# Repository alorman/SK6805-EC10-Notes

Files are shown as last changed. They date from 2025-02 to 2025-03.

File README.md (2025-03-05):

# SK6805-EC10-Notes

Notes on the __smallest__ availible addressable LED to date!

**Author's note:** While you will definitely need a loupe or microscope to even see what you're doing, these can be a bit easier to solder than the 3535 and other large sizes. If you choose a low-temp solder and gently use hot air, you can get each LED to snap into place onto the solder pads. 

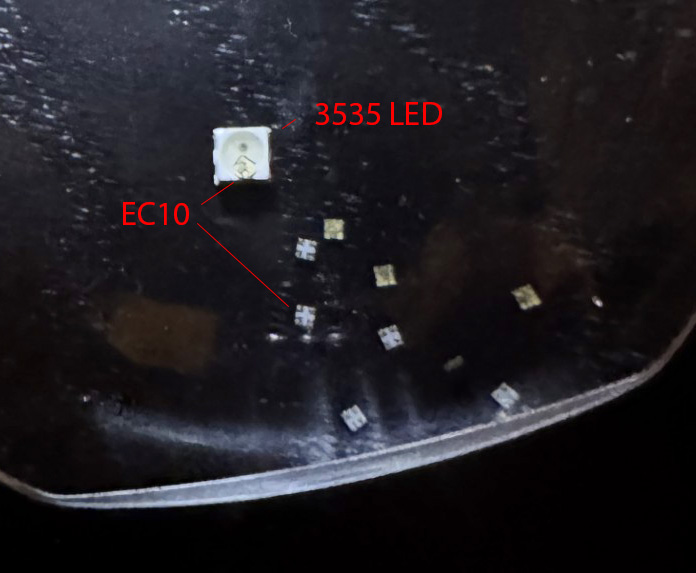
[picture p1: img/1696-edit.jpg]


Above, you can see the EC10 modules next to a 3535 LED. These guys are SMOL.

## Purchasing
Adadfruit sells thes units as [Part Number 5849](https://www.adafruit.com/product/5849).
They can also be purchased on AliExpress in volume.  
Buy extras, you will lose some of these, since breathing on them the wrong way blows them away. 

## Datasheet 
[Datasheet from Adafruit](https://cdn-shop.adafruit.com/product-files/5849/SK6805-EC10-000_REV.01_EN.pdf)

## KiCad Files
I made footprint and symbol files availible for the EC10s.  
They can be found in `\SK6805-EC10-kicad-libraries`  
There is no 3d model included, because it didn't add much and made it much harder to see if the mask was right.  

## Test Fixture
Since I couldn't find a pre-made strip of the EC10 modules, I decided to make one. This can be easily fabbed from your favorite fab house. 
Full KiCad 8 files can be found in `\EC10-Test-PCB` 

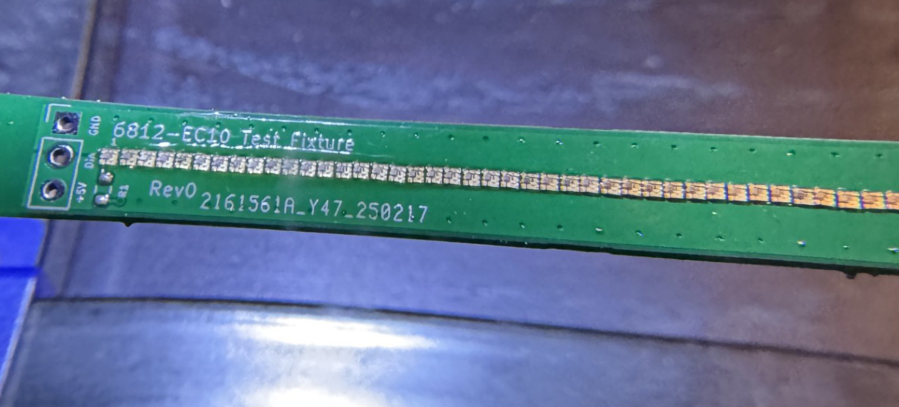
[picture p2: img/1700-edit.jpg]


## Power Profiling
I soldered 48 of the modules to my test fixture (2 got blown away by the hot air gun).
**Note** use low-temp solder and gentle hot air. I was able to swim the modules into place on flux without breaking any of the lenses. At least on the 1515, if you get them too hot, the lens/case breaks. 

### Setup
I connected my 48x strip to a Siglent SPD-3303X PSU that quotes current reading of +- 0.3% + 10ma, while there may be tiny test errors, this should provide a good bassis for power calculations. 

I used 5V as a supply voltage.

### Methodology
I cycled Red, Green then Blue through 0-255 individually, while recording the power usage. Then I ran all three together to make white from 0-255. 

The code can be found in `\test-code` and is designed for a Teensy, but would work on any Arduino. 

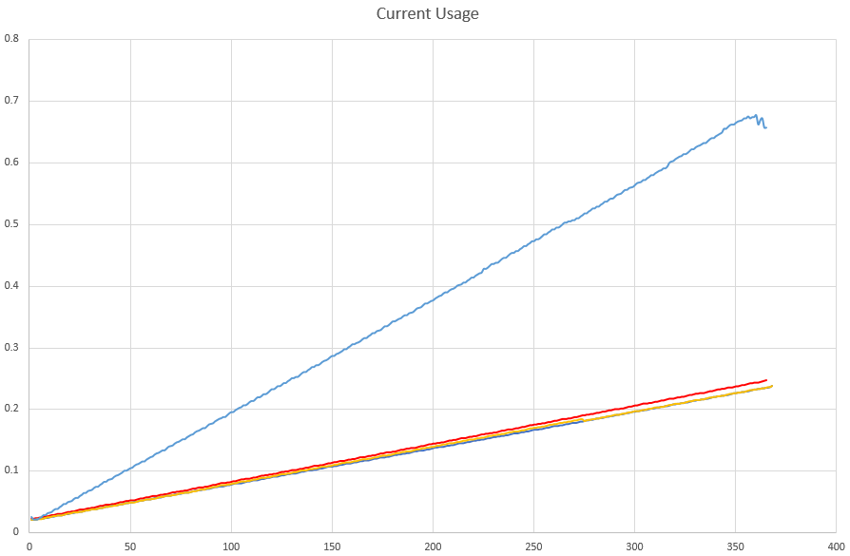
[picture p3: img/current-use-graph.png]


We can see a linear and similar progression for R, G and B. Correspondingly, we see that consumption roughly tripling for white, which makes sense.

The idle current can also be charachterized from the first few data points.

## Power Formula

### I<sub>consumed</sub>=((R+B+G)*0.013838)+0.4791

Where:  
`Iconsumed` = Current consumed **per LED** in mA  
`(R+B+G)` = Values for R, G and B in 0-255  
`0.4791` = Idle current draw in mA per module  

## Compared To 1515 Size
These are a good amount smaller than the pettite 1515 size. I documented the features of those [on this repo](https://github.com/alorman/sk6805-1515-info).

Here are the two compared:  

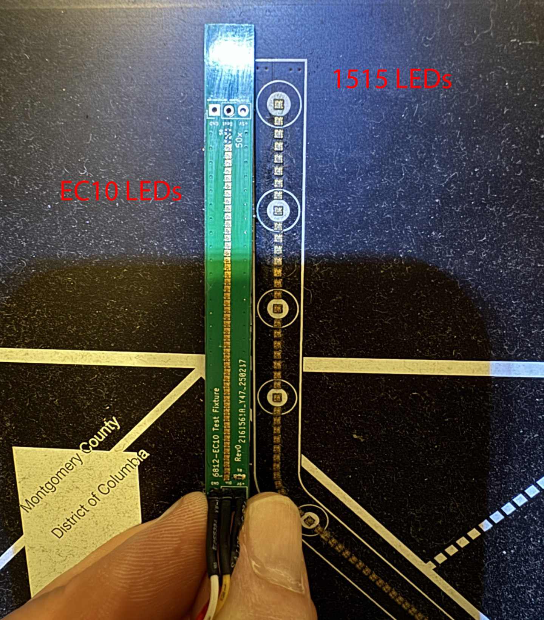
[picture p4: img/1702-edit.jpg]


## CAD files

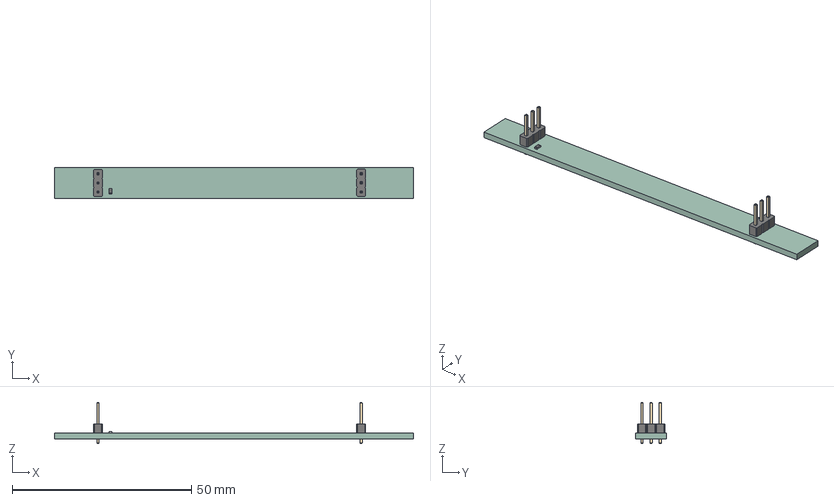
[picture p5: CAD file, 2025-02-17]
EC10-Test-PCB/Outputs/STEP/EC10-Test-PCB.step
100.1 x 8.70 x 11.5 mm
R_0603_1608Metric
PinHeader_1x03_P254mm_Vertical x 2
EC10-Test-PCB_PCB

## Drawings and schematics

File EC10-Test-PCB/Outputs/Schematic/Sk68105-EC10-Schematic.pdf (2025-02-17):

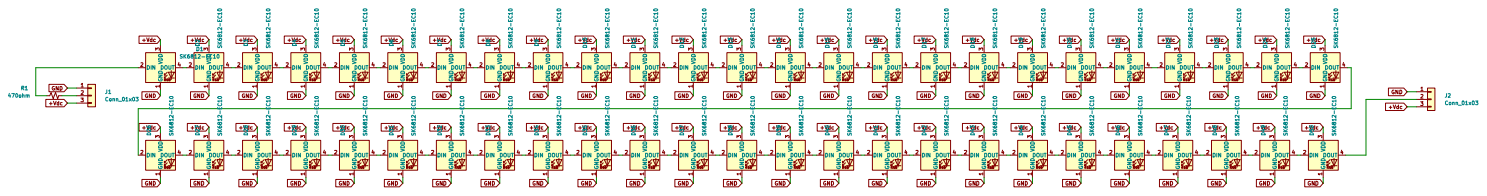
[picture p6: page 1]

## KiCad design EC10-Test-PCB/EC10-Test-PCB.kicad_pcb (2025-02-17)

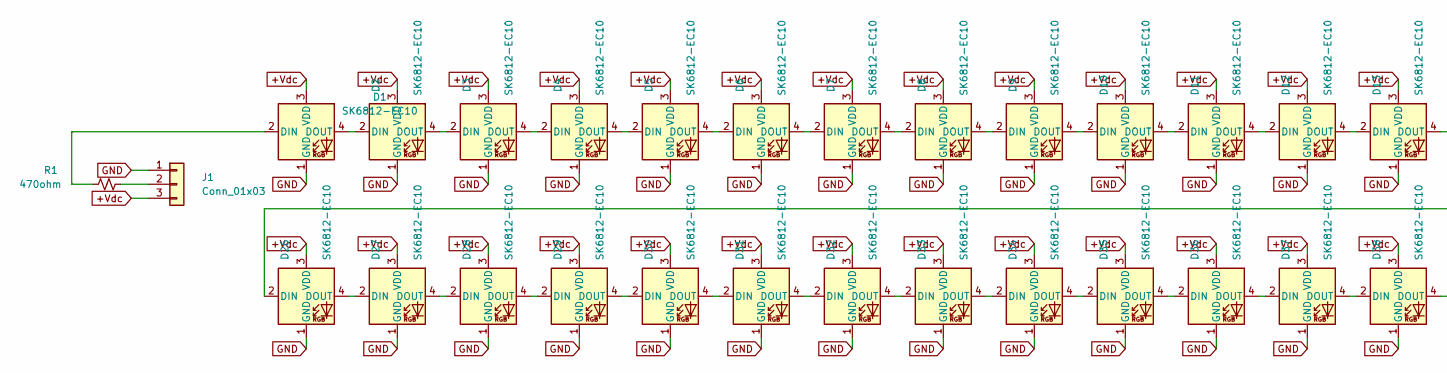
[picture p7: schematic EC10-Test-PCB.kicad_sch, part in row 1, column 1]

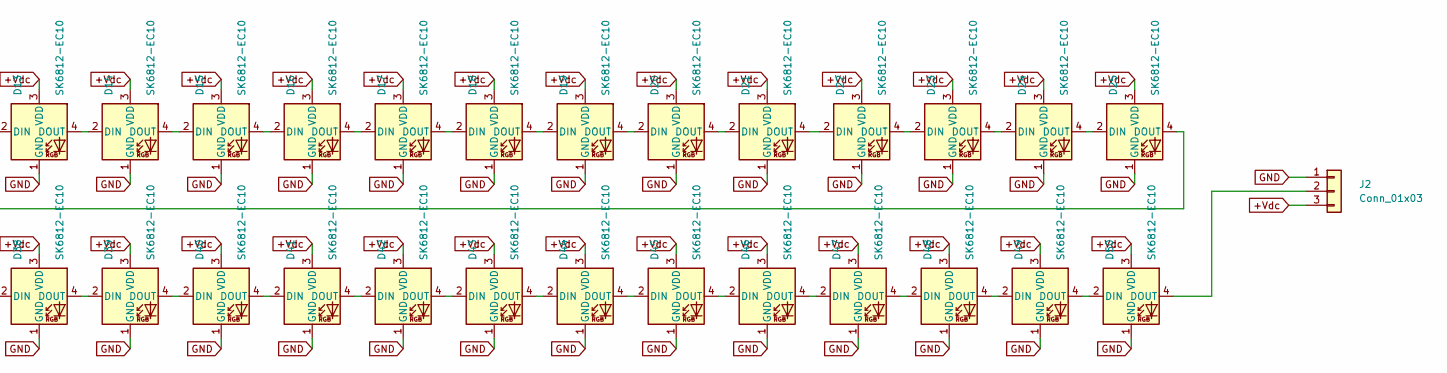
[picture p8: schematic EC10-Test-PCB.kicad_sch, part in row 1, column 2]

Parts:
D1, D2, D3, D4, D5, D6, D7, D8, D9, D10, D11, D12, D13, D14, D15, D16, D17, D18, D19, D20, D21, D22, D23, D24, D25, D26, D27, D28, D29, D30, D31, D32, D33, D34, D35, D36, D37, D38, D39, D40, D41, D42, D43, D44, D45, D46, D47, D48, D49, D50: SK6812-EC10; SK6805-EC10
J1, J2: Conn_01x03; PinHeader_1x03_P2.54mm_Vertical
R1: 470ohm; R_0603_1608Metric

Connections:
+Vdc: D1.3 (VDD), D2.3 (VDD), D3.3 (VDD), D4.3 (VDD), D5.3 (VDD), D6.3 (VDD), D7.3 (VDD), D8.3 (VDD), D9.3 (VDD), D10.3 (VDD), D11.3 (VDD), D12.3 (VDD), D13.3 (VDD), D14.3 (VDD), D15.3 (VDD), D16.3 (VDD), D17.3 (VDD), D18.3 (VDD), D19.3 (VDD), D20.3 (VDD), D21.3 (VDD), D22.3 (VDD), D23.3 (VDD), D24.3 (VDD), D25.3 (VDD), D26.3 (VDD), D27.3 (VDD), D28.3 (VDD), D29.3 (VDD), D30.3 (VDD), D31.3 (VDD), D32.3 (VDD), D33.3 (VDD), D34.3 (VDD), D35.3 (VDD), D36.3 (VDD), D37.3 (VDD), D38.3 (VDD), D39.3 (VDD), D40.3 (VDD), D41.3 (VDD), D42.3 (VDD), D43.3 (VDD), D44.3 (VDD), D45.3 (VDD), D46.3 (VDD), D47.3 (VDD), D48.3 (VDD), D49.3 (VDD), D50.3 (VDD), J1.3, J2.3
GND: D1.1 (GND), D2.1 (GND), D3.1 (GND), D4.1 (GND), D5.1 (GND), D6.1 (GND), D7.1 (GND), D8.1 (GND), D9.1 (GND), D10.1 (GND), D11.1 (GND), D12.1 (GND), D13.1 (GND), D14.1 (GND), D15.1 (GND), D16.1 (GND), D17.1 (GND), D18.1 (GND), D19.1 (GND), D20.1 (GND), D21.1 (GND), D22.1 (GND), D23.1 (GND), D24.1 (GND), D25.1 (GND), D26.1 (GND), D27.1 (GND), D28.1 (GND), D29.1 (GND), D30.1 (GND), D31.1 (GND), D32.1 (GND), D33.1 (GND), D34.1 (GND), D35.1 (GND), D36.1 (GND), D37.1 (GND), D38.1 (GND), D39.1 (GND), D40.1 (GND), D41.1 (GND), D42.1 (GND), D43.1 (GND), D44.1 (GND), D45.1 (GND), D46.1 (GND), D47.1 (GND), D48.1 (GND), D49.1 (GND), D50.1 (GND), J1.1, J2.1
unnamed: D1.2 (DIN), R1.1
unnamed: D1.4 (DOUT), D2.2 (DIN)
unnamed: D2.4 (DOUT), D3.2 (DIN)
unnamed: D3.4 (DOUT), D4.2 (DIN)
unnamed: D4.4 (DOUT), D5.2 (DIN)
unnamed: D5.4 (DOUT), D6.2 (DIN)
unnamed: D6.4 (DOUT), D7.2 (DIN)
unnamed: D7.4 (DOUT), D8.2 (DIN)
unnamed: D8.4 (DOUT), D9.2 (DIN)
unnamed: D9.4 (DOUT), D10.2 (DIN)
unnamed: D10.4 (DOUT), D11.2 (DIN)
unnamed: D11.4 (DOUT), D12.2 (DIN)
unnamed: D12.4 (DOUT), D13.2 (DIN)
unnamed: D13.4 (DOUT), D14.2 (DIN)
unnamed: D14.4 (DOUT), D15.2 (DIN)
unnamed: D15.4 (DOUT), D16.2 (DIN)
unnamed: D16.4 (DOUT), D17.2 (DIN)
unnamed: D17.4 (DOUT), D18.2 (DIN)
unnamed: D18.4 (DOUT), D19.2 (DIN)
unnamed: D19.4 (DOUT), D20.2 (DIN)
unnamed: D20.4 (DOUT), D21.2 (DIN)
unnamed: D21.4 (DOUT), D22.2 (DIN)
unnamed: D22.4 (DOUT), D23.2 (DIN)
unnamed: D23.4 (DOUT), D24.2 (DIN)
unnamed: D24.4 (DOUT), D25.2 (DIN)
unnamed: D25.4 (DOUT), D26.2 (DIN)
unnamed: D26.4 (DOUT), D27.2 (DIN)
unnamed: D27.4 (DOUT), D28.2 (DIN)
unnamed: D28.4 (DOUT), D29.2 (DIN)
unnamed: D29.4 (DOUT), D30.2 (DIN)
unnamed: D30.4 (DOUT), D31.2 (DIN)
unnamed: D31.4 (DOUT), D32.2 (DIN)
unnamed: D32.4 (DOUT), D33.2 (DIN)
unnamed: D33.4 (DOUT), D34.2 (DIN)
unnamed: D34.4 (DOUT), D35.2 (DIN)
unnamed: D35.4 (DOUT), D36.2 (DIN)
unnamed: D36.4 (DOUT), D37.2 (DIN)
unnamed: D37.4 (DOUT), D38.2 (DIN)
unnamed: D38.4 (DOUT), D39.2 (DIN)
unnamed: D39.4 (DOUT), D40.2 (DIN)
unnamed: D40.4 (DOUT), D41.2 (DIN)
unnamed: D41.4 (DOUT), D42.2 (DIN)
unnamed: D42.4 (DOUT), D43.2 (DIN)
unnamed: D43.4 (DOUT), D44.2 (DIN)
unnamed: D44.4 (DOUT), D45.2 (DIN)
unnamed: D45.4 (DOUT), D46.2 (DIN)
unnamed: D46.4 (DOUT), D47.2 (DIN)
unnamed: D47.4 (DOUT), D48.2 (DIN)
unnamed: D48.4 (DOUT), D49.2 (DIN)
unnamed: D49.4 (DOUT), D50.2 (DIN)
unnamed: D50.4 (DOUT), J2.2
unnamed: J1.2, R1.2

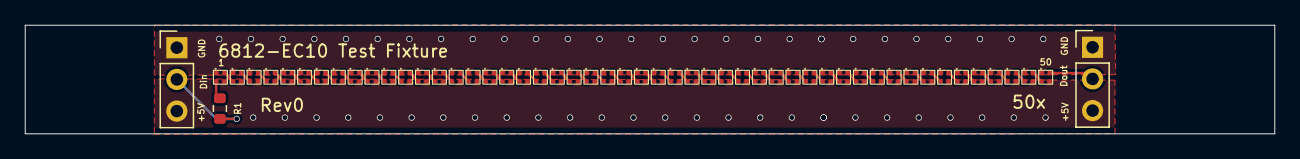
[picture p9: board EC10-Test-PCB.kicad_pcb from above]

Board: 2 copper layers, 100.1 x 8.7 mm, 53 parts (0 on the bottom side), 54 nets.

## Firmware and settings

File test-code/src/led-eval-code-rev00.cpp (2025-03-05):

// A test pogram to have neopixels move on user input.

#include <Adafruit_NeoPixel.h>

//Define LED Pin
#define LED_PIN  26

//Define LED Count
#define LED_COUNT 48

// //Define Touch Pin
// #define TOUCH_PIN A9

//functions declarations 
void colorIncrement(Adafruit_NeoPixel &strip, uint16_t timeInterval);

//Establish the neopixle object
Adafruit_NeoPixel TestStrip(LED_COUNT, LED_PIN, NEO_GRB + NEO_KHZ800);

//Define LED Variables
uint8_t RGBcolor [] = {0,0,0};
uint32_t TestColorRGB = TestStrip.Color(RGBcolor[0],RGBcolor[1],RGBcolor[2]);

uint16_t LEDColorH = 100;
uint8_t LEDColorS = 100;
uint8_t LEDColorV = 0;

uint32_t LEDColorHSV = 0;
uint32_t ConvertedHSVtoRGB = 0;

//Define touch variables
uint8_t touchValue = 0;

void setup() {
  Serial.begin(115200); //establish serial port
  delay(1500);
  TestStrip.begin();
  TestStrip.setBrightness(255); //using this to have the values we input be fully deterministic
  TestStrip.clear();
  TestStrip.show();
  
  Serial.println("Setup Complete...");
  Serial.println("Starting..."); //nice confirmation that it's actually working
  delay(500);
}

void loop() {
  // while (touchRead(TOUCH_PIN) > 1800) {
  //   ConvertedHSVtoRGB = TestStrip.gamma32(TestStrip.ColorHSV(LEDColorH, LEDColorS, LEDColorV));
  //   TestStrip.fill(ConvertedHSVtoRGB);
  //   uint8_t ColorR = ConvertedHSVtoRGB >> 16;  
  //   uint8_t ColorG = ConvertedHSVtoRGB >> 8;
  //   uint8_t ColorB = ConvertedHSVtoRGB;
  //   //Serial.println((String)"LED Value is H:" + LEDColorH + " S:" + LEDColorS + " V:" + LEDColorV);
  //   Serial.println((String)"Converted RGB is:" + ConvertedHSVtoRGB + " R:" + ColorR + " G:" + ColorB + " B:" + ColorB);
  //   TestStrip.show();
  //   delay(1000);
  //   Serial.println("Great! Next!");
  //   LEDColorV++;
  // }
  colorIncrement(TestStrip, 750);

}

void colorIncrement(Adafruit_NeoPixel &strip, uint16_t timeInterval) {
  // 1. Increment Red
  for (int i = 0; i < 256; i++) {
    strip.fill(strip.Color(i, 0, 0), 0, strip.numPixels());
    strip.show();

    // Print serial feedback
    Serial.print("R=");
    Serial.print(i);
    Serial.print(", G=0, B=0  ");
    Serial.println(" (Incrementing Red)");

    delay(timeInterval);
  }
  // Go Black
  strip.fill(strip.Color(0, 0, 0), 0, strip.numPixels());
  strip.show();
  Serial.println("All pixels set to Black");
  delay(timeInterval);

  // 2. Increment Green
  for (int i = 0; i < 256; i++) {
    strip.fill(strip.Color(0, i, 0), 0, strip.numPixels());
    strip.show();

    // Print serial feedback
    Serial.print("R=0, G=");
    Serial.print(i);
    Serial.print(", B=0  ");
    Serial.println(" (Incrementing Green)");

    delay(timeInterval);
  }
  // Go Black
  strip.fill(strip.Color(0, 0, 0), 0, strip.numPixels());
  strip.show();
  Serial.println("All pixels set to Black");
  delay(timeInterval);

  // 3. Increment Blue
  for (int i = 0; i < 256; i++) {
    strip.fill(strip.Color(0, 0, i), 0, strip.numPixels());
    strip.show();

    // Print serial feedback
    Serial.print("R=0, G=0, B=");
    Serial.print(i);
    Serial.println(" (Incrementing Blue)");

    delay(timeInterval);
  }
  // Go Black
  strip.fill(strip.Color(0, 0, 0), 0, strip.numPixels());
  strip.show();
  Serial.println("All pixels set to Black");
  delay(timeInterval);

  // 4. Increment White for an RGB strip by increasing R=G=B:
  for (int i = 0; i < 256; i++) {
    // "White" on an RGB strip is full R, G, and B in equal amounts:
    strip.fill(strip.Color(i, i, i), 0, strip.numPixels());
    strip.show();

    // Print serial feedback
    Serial.print("R=");
    Serial.print(i);
    Serial.print(", G=");
    Serial.print(i);
    Serial.print(", B=");
    Serial.print(i);
    Serial.println("  (Incrementing White on RGB strip)");

    delay(5000);
  }
}

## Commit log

2025-02-17 test pcb release to fab
    [EC10-Test-PCB-B_Cu.gbr, EC10-Test-PCB-B_Mask.gbr, EC10-Test-PCB-B_Paste.gbr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]
2025-03-05 add notes, pcb files, results and photos
